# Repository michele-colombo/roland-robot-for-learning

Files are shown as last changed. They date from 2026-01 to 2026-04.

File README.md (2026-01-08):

# ROLAND: a RObot for Learning Autonomous Navigation and Detection
ROLAND is a modular robotics project developed as a learning platform for autonomous navigation, SLAM, sensor fusion, and 3D reconstruction.
The system is built around a differential-drive mobile base and is designed to evolve over time as new sensing, perception, and actuation modules are added.

High-level autonomy runs on an NVIDIA Jetson Orin Nano, while low-level control is handled by an ESP32 driving brushless motors with FOC control.
The robot features self-designed, 3D-printed parts.

## Roadmap
- [x] Differential drive base
- [ ] Add 2D LiDAR and off-the-shelf SLAM module
- [ ] Add stereo camera and 3D mapping of the scene
- [ ] Implement object seeking from image reference
- [ ] Add a manipulator for grabbing the object?

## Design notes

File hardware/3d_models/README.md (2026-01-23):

Original onshape project can be found here: https://cad.onshape.com/documents/1359bf2a92ebeb07a983a6f3/w/c33c9e913b42d0126ce1f26a/e/81632e9f34f59df6b4129b4c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

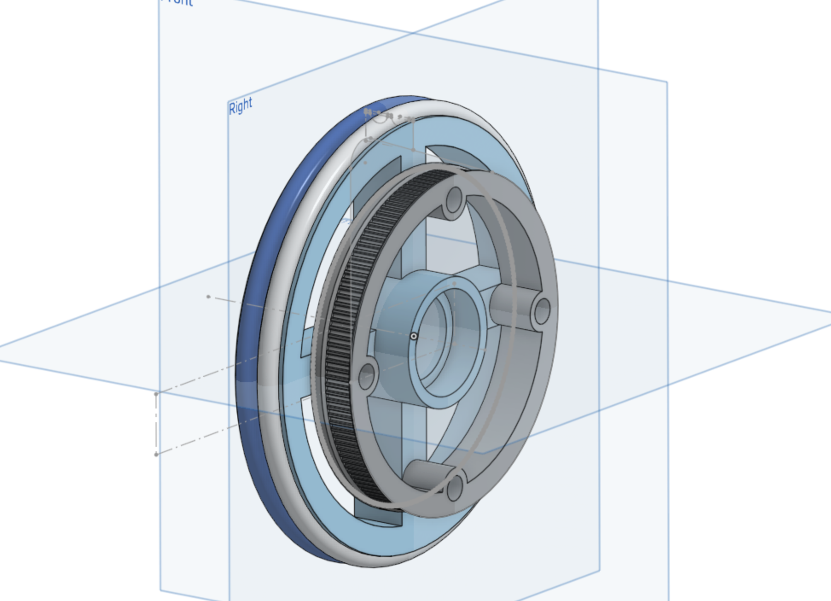
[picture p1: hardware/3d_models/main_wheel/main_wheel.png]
main_wheel


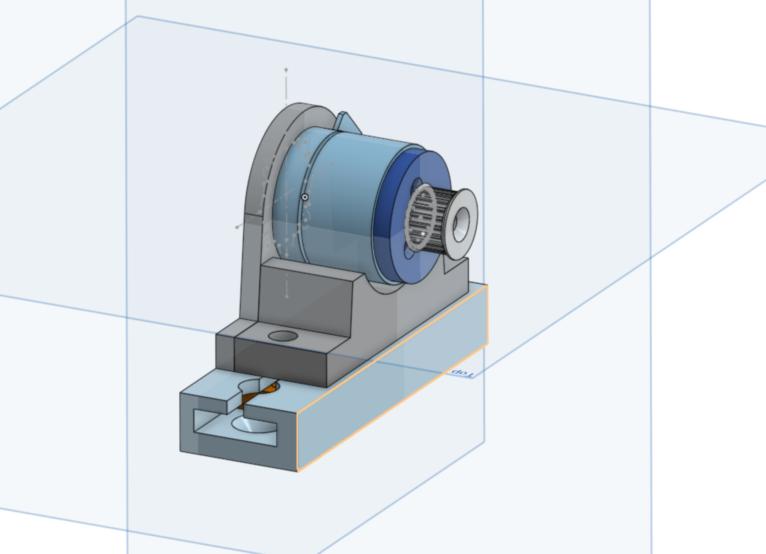
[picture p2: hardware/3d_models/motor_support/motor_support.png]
motor_support


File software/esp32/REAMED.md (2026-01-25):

# ESP32 code

This folder contains code to be uploaded on ESP32(s) to manage low-level interaction with sensors and actuators.

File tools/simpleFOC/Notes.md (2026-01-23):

# Notes
- If you lower the voltage limit (like `motor.voltage_limit = 4;`) you get a lower maximum speed and lower torwue, but also a much smoother and quiter movement (maybe also cooler motor, to check).
- Maybe the speed of the control loop impacts on the motor temperature: it seems that a faster control loop keeps the motor cooler. Probably is asking to the motor a speed higher than the one it can reach that increases temperature.
- You need to call `motor.loopFOC()` at least once before calling `motor.move(target)`, thus they must be in the correct order in the control loop.

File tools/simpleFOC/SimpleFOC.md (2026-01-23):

# SimpleFOC library

## Install SimpleFOC library in Arduino IDE

See the [doc](https://docs.simplefoc.com/library_download).
Briefly:
- Open Arduino IDE and start Arduino Library Manager by clicking: `Tools > Manage Libraries....`
- Search for "Simple FOC" library and install the latest version.
- Reopen Arduino IDE and you should have the library examples in `File > Examples > Simple FOC`.

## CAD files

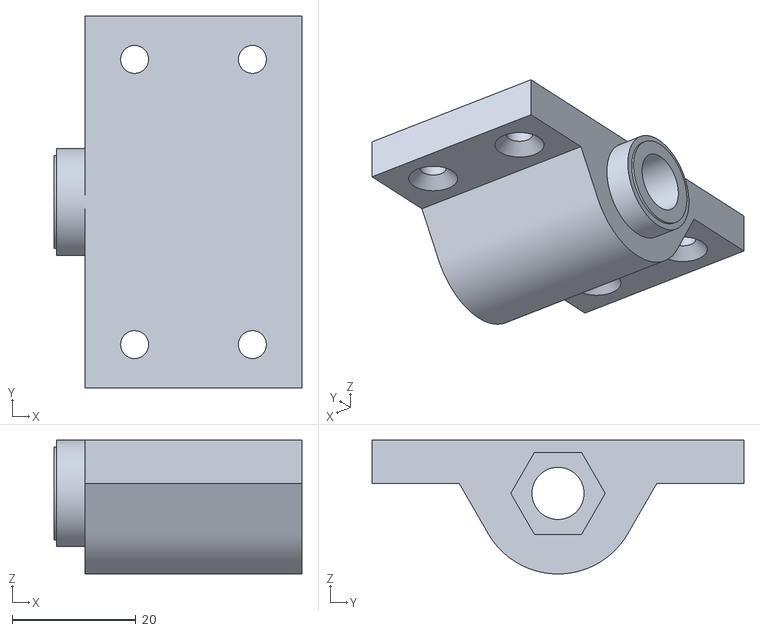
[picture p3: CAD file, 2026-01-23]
hardware/3d_models/main_wheel/main_wheel_support - support.stl
40.0 x 60.0 x 21.6

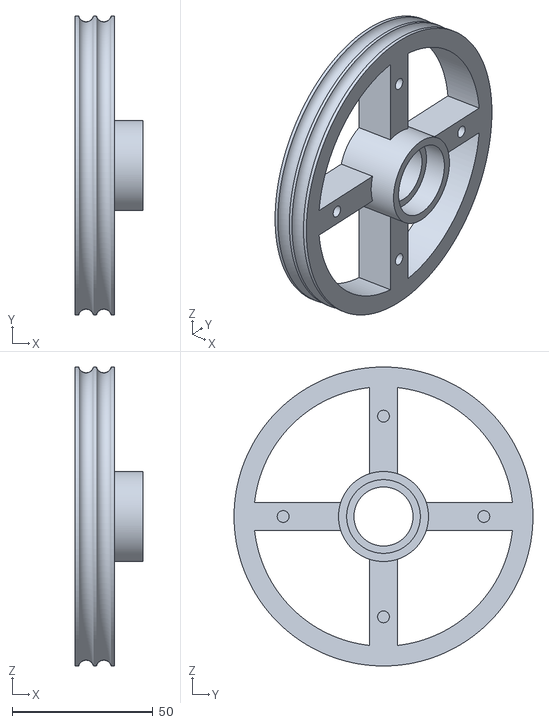
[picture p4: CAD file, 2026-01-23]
hardware/3d_models/main_wheel/main_wheel - wheel.stl
24.0 x 106.3 x 106.3

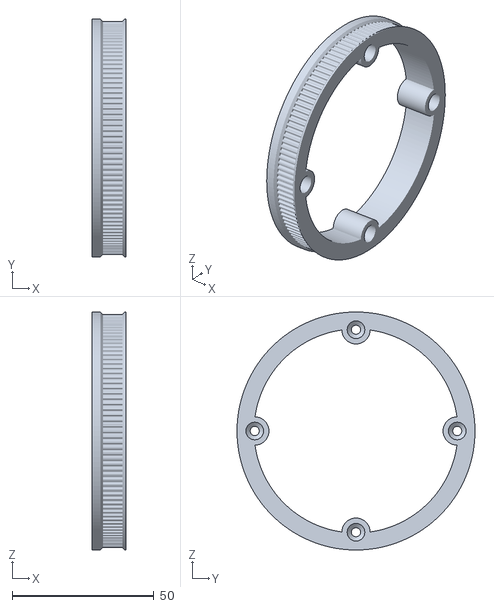
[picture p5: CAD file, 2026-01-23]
hardware/3d_models/main_wheel/main_wheel - pulley.stl
12.0 x 83.9 x 83.9

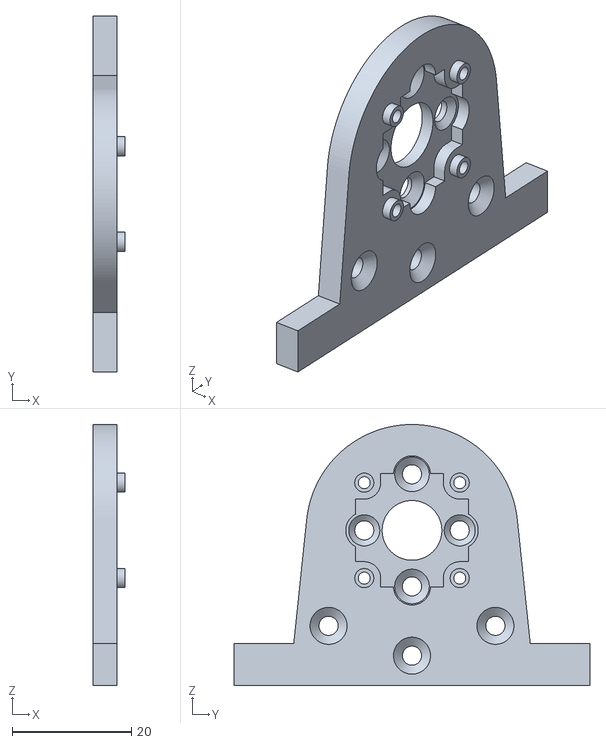
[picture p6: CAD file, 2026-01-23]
hardware/3d_models/motor_support/motor_support - support_1.stl
5.40 x 59.7 x 43.8

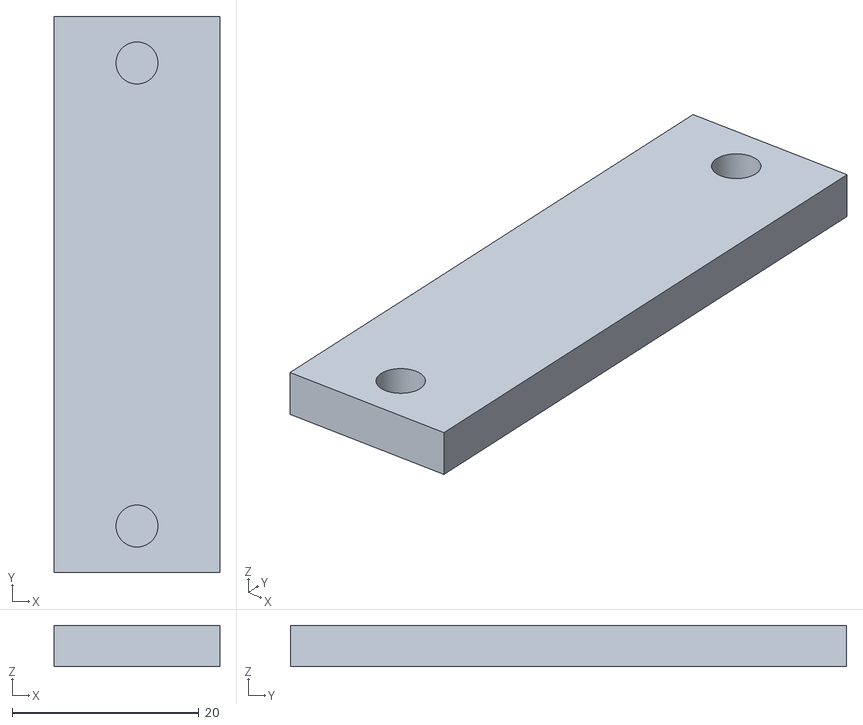
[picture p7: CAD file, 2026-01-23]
hardware/3d_models/motor_support/motor_support - slider_2.stl
17.8 x 59.7 x 4.40

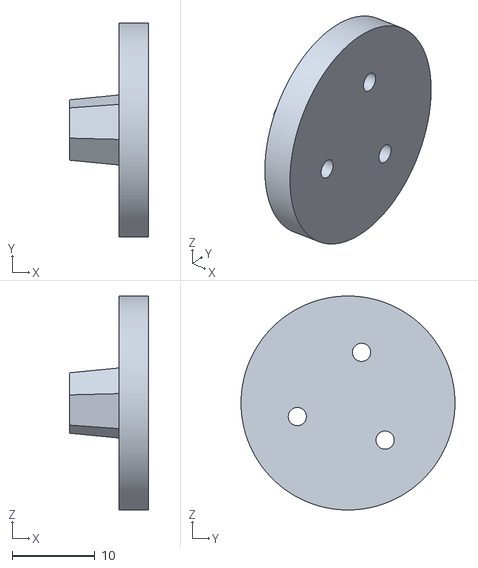
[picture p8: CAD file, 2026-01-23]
hardware/3d_models/motor_support/motor_support - pulley_support.stl
9.60 x 25.9 x 25.9

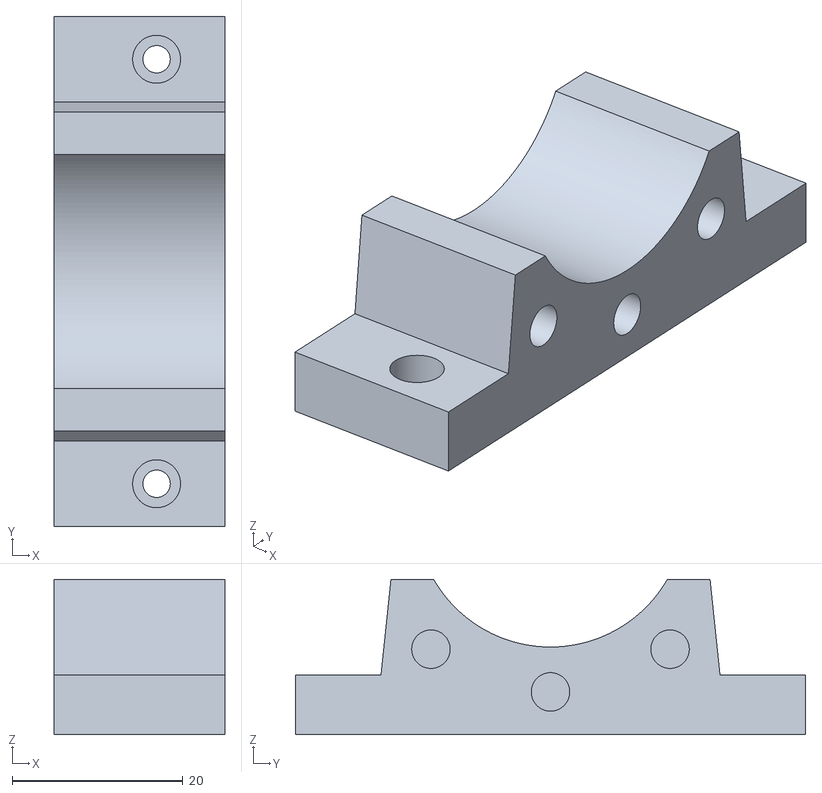
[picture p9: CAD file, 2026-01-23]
hardware/3d_models/motor_support/motor_support - support_2.stl
20.0 x 59.7 x 18.2

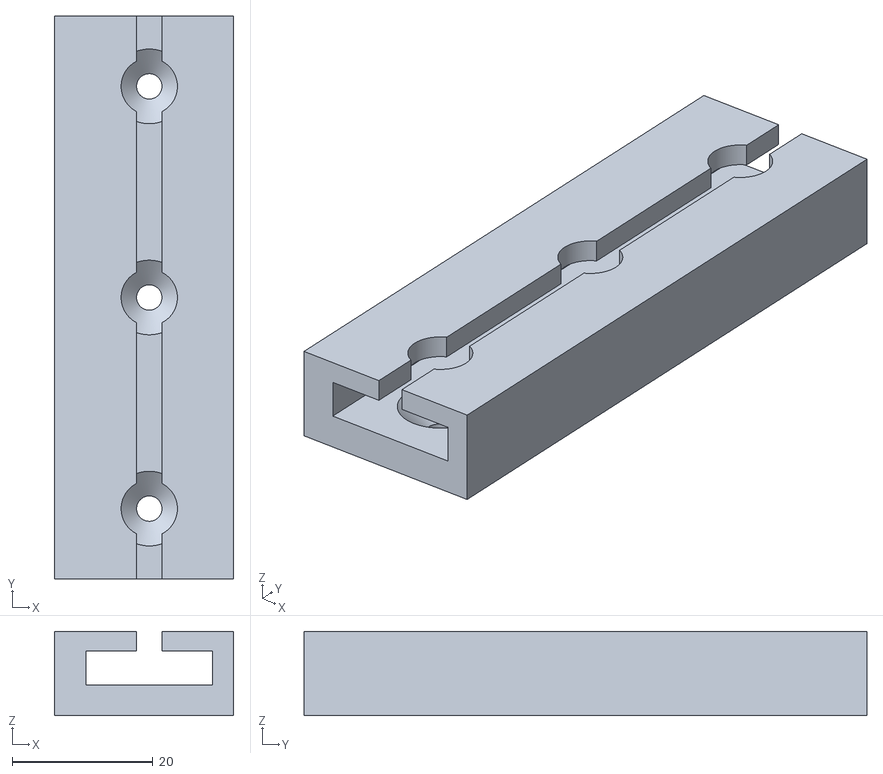
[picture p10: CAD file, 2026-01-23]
hardware/3d_models/motor_support/motor_support - slider.stl
25.5 x 80.0 x 12.0

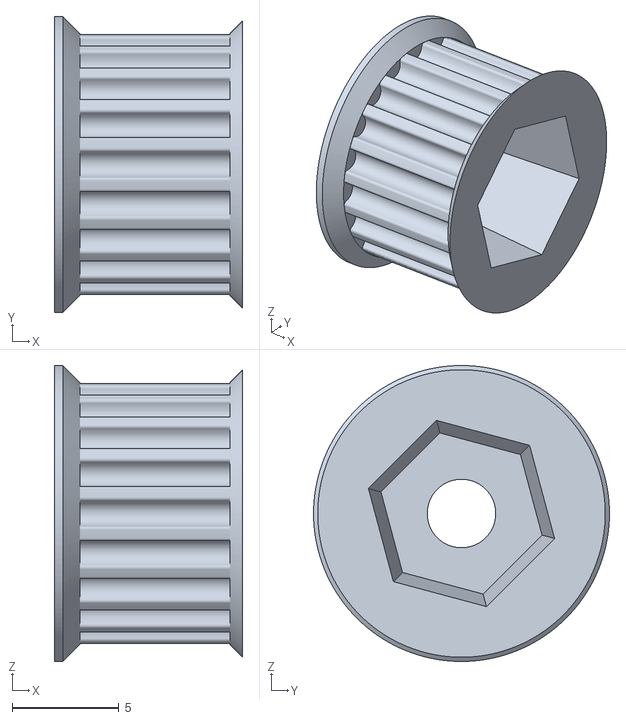
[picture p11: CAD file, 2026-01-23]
hardware/3d_models/motor_support/motor_support - pulley.stl
8.80 x 13.8 x 13.8

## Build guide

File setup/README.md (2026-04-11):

# Setup

## Jetson

- Connect base ESP32, gimbal ESP32, ZED and LiDAR to USB ports of Jetson
- Since both my ESP32 and LiDAR use the same CP2102 chip I cannot use `serial/by-id` to distinguish between them. Therefore I rely on their stable physical connection (you must connect them always to the same port) and use the USB path to the port they are connected to.
    - In order to find the correct USB port path you can use `udevadm monitor --property | grep DEVPATH` and plug/unplug the different devices.
    - Set their address in `setup/jetson/rules/robot.rules`.
    - Run `./setup/jetson/rules/created_udev_rules.sh` to install the rules
    - You should now see `/dev/esp32-base`, `/dev/esp32-gimbal` and `/dev/ldlidar` (with all the devices connected).

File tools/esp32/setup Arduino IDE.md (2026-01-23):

# Setup Arduino IDE (for ESP32)
## Install
Easiest way to get Arduino IDE is probably using flatpak.

```shell
flatpak install flathub cc.arduino.IDE2
```

You may need to add flathub to the current user before (only needed once):
```shell
flatpak remote-add --user --if-not-exists flathub https://flathub.org/repo/flathub.flatpakrepo
```

Add current user to dialout:
```shell
sudo usermod -a -G dialout $USER
```
Then it is necessary to log out and back in.

## Setup for ESP32
 You can check [this tutorial](https://randomnerdtutorials.com/installing-the-esp32-board-in-arduino-ide-windows-instructions/) as reference.

 Basically it's adding the following line in File>Preferences>Additionl Boards Managers URLs:
 ```
 https://raw.githubusercontent.com/espressif/arduino-esp32/gh-pages/package_esp32_index.json, http://arduino.esp8266.com/stable/package_esp8266com_index.json
 ```

 and installing `esp32` board manager by `Expressif Systems` (from Tools > Board > Boards Manager)

 Then select the board. Currently I'm testing with an ESP32-WROOM-32 (from AZ-Delivery) and it works by selecting ESP32-WROOM-DA.

 ## Troubleshooting
 ### Apparent flash failure
 Even if you get an output like this:
```
Writing at 0x000e4078 [============================> ]  98.1% 557056/567916 bytes... 

Writing at 0x000e7ce0 [==============================] 100.0% 567916/567916 bytes... 
Wrote 883936 bytes (567916 compressed) at 0x00010000 in 9.0 seconds (788.8 kbit/s).
Hash of data verified.

Hard resetting via RTS pin...
```
the flashing was actually successful.

### Flash failure
Sometimes flashing fails the first time, usually trying again solves the issue.

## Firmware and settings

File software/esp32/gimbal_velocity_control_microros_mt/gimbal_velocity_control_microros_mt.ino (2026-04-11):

#include <micro_ros_arduino.h>
#include <SimpleFOC.h>

#include <rcl/rcl.h>
#include <rcl/error_handling.h>
#include <rclc/rclc.h>
#include <rclc/executor.h>

#include <std_msgs/msg/float32.h>

// ================================================================
// Pins
// ================================================================
// SPI (AS5048) pins
const int pin_spi_mosi = 23;
const int pin_spi_miso = 19;
const int pin_spi_clk  = 18;
const int pin_cs_yaw   = 2;
const int pin_cs_pitch = 0;

// Yaw motor
const int pin_yaw_in1 = 14;
const int pin_yaw_in2 = 27;
const int pin_yaw_in3 = 26;

// Pitch motor
const int pin_pitch_in1 = 25;
const int pin_pitch_in2 = 33;
const int pin_pitch_in3 = 32;

// ================================================================
// Motor params
// ================================================================
const int   motor_pole_pairs      = 11;
const float motor_phase_resistance = 5.50f / 2.0f;
const float motor_voltage_supply  = 12.0f;
const float motor_voltage_limit   = 6.0f;
const float motor_PID_velocity_P  = 0.2f;
const float motor_PID_velocity_I  = 1.0f;
const float motor_PID_velocity_D  = 0.0f;
const float motor_PID_velocity_output_ramp = 100.0f;
const float motor_LPF_velocity_Tf = 0.05f;

// ================================================================
// micro-ROS
// ================================================================
rclc_executor_t executor;
rclc_support_t support;
rcl_allocator_t allocator;
rcl_node_t node;

rcl_timer_t curr_vel_timer;
const int curr_vel_pub_period = 100; // ms

// ================================================================
// MotorSide
// ================================================================
struct MotorSide
{
  // FOC
  MagneticSensorSPI sensor;
  BLDCMotor motor;
  BLDCDriver3PWM driver;

  // Control
  float targetVelocity;
  float lastAngle;
  bool  initialized;

  // micro-ROS
  const char* cmdTopic;
  const char* currTopic;

  rcl_subscription_t cmdSub;
  rcl_publisher_t    currPub;

  std_msgs__msg__Float32 cmdMsg;
  std_msgs__msg__Float32 currMsg;

  MotorSide(int in1, int in2, int in3, int csPin)
  : sensor(AS5048_SPI, csPin)
  , motor(motor_pole_pairs, motor_phase_resistance)
  , driver(in1, in2, in3)
  , targetVelocity(0.0f)
  , lastAngle(0.0f)
  , initialized(false)
  {}
};

// ================================================================
// Yaw / Pitch motors
// ================================================================
MotorSide motorYaw(
  pin_yaw_in1, pin_yaw_in2, pin_yaw_in3, pin_cs_yaw);

MotorSide motorPitch(
  pin_pitch_in1, pin_pitch_in2, pin_pitch_in3, pin_cs_pitch);

// Convenience array
MotorSide* motors[] = { &motorYaw, &motorPitch };
constexpr int motorCount = 2;

// ================================================================
// micro-ROS callbacks
// ================================================================
void handle_cmd_vel(MotorSide& m, const void* msgin)
{
  const auto* msg = static_cast<const std_msgs__msg__Float32*>(msgin);
  m.targetVelocity = msg->data;
}

void cmd_vel_yaw_cbk(const void* msgin)
{
  handle_cmd_vel(motorYaw, msgin);
}

void cmd_vel_pitch_cbk(const void* msgin)
{
  handle_cmd_vel(motorPitch, msgin);
}

void curr_vel_timer_cbk(rcl_timer_t* timer, int64_t)
{
  if (!timer) return;

  static int64_t lastTime = 0;
  int64_t now = esp_timer_get_time();
  float dt = (now - lastTime) / 1e6f;
  lastTime = now;

  if (dt <= 0.0f) return;

  for (int i = 0; i < motorCount; ++i) {
    MotorSide& m = *motors[i];

    float angle = m.sensor.getAngle();
    float velocity = (angle - m.lastAngle) / dt;
    m.lastAngle = angle;

    m.currMsg.data = velocity;
    rcl_publish(&m.currPub, &m.currMsg, NULL);
  }
}

// ================================================================
// Helpers
// ================================================================

// Safe to call before driver.init(): forces all PWM pins LOW at the GPIO level.
// motor.disable() / driver.disable() must NOT be called before driver.init()
// because driver->params is nullptr until then, causing a null-pointer crash
// inside _writeDutyCycle3PWM on ESP32.
void safeMotorPinsLow()
{
  const int pins[] = {
    pin_yaw_in1,   pin_yaw_in2,   pin_yaw_in3,
    pin_pitch_in1, pin_pitch_in2, pin_pitch_in3
  };
  for (int pin : pins) {
    pinMode(pin, OUTPUT);
    digitalWrite(pin, LOW);
  }
}

void disableAllMotors()
{
  for (int i = 0; i < motorCount; ++i)
    motors[i]->motor.disable();
}

bool allMotorsInitialized()
{
  for (int i = 0; i < motorCount; ++i)
    if (!motors[i]->initialized) return false;
  return true;
}

void initMotor(MotorSide& m)
{
  m.sensor.init();
  m.motor.linkSensor(&m.sensor);

  m.driver.voltage_power_supply = motor_voltage_supply;
  m.driver.init();
  m.motor.linkDriver(&m.driver);

  m.motor.controller = MotionControlType::velocity;
  m.motor.PID_velocity.P = motor_PID_velocity_P;
  m.motor.PID_velocity.I = motor_PID_velocity_I;
  m.motor.PID_velocity.D = motor_PID_velocity_D;
  m.motor.PID_velocity.output_ramp = motor_PID_velocity_output_ramp;
  m.motor.voltage_limit = motor_voltage_limit;
  m.motor.LPF_velocity.Tf = motor_LPF_velocity_Tf;

  m.motor.init();
  m.initialized = m.motor.initFOC();
}

void initMotorRos(MotorSide& m, rclc_subscription_callback_t cbk)
{
  rclc_publisher_init_best_effort(
    &m.currPub,
    &node,
    ROSIDL_GET_MSG_TYPE_SUPPORT(std_msgs, msg, Float32),
    m.currTopic);

  rclc_subscription_init_best_effort(
    &m.cmdSub,
    &node,
    ROSIDL_GET_MSG_TYPE_SUPPORT(std_msgs, msg, Float32),
    m.cmdTopic);

  rclc_executor_add_subscription(
    &executor,
    &m.cmdSub,
    &m.cmdMsg,
    cbk,
    ON_NEW_DATA);
}

// ================================================================
// Tasks
// ================================================================
void ros_loop(void*)
{
  while (1) {
    rclc_executor_spin_some(&executor, RCL_MS_TO_NS(10));
    vTaskDelay(pdMS_TO_TICKS(1));
  }
}

void control_loop(void*)
{
  while (1) {
    for (int i = 0; i < motorCount; ++i) {
      MotorSide& m = *motors[i];
      m.motor.loopFOC();
      m.motor.move(m.targetVelocity);
    }
  }
}

// ================================================================
// Setup
// ================================================================
void setup()
{
  // Force all motor PWM pins low immediately, before anything else.
  // This is to ensure output pins are in a known safe state even if
  // micro-ROS or motor init fails and prevent them from heating up due to DC lock.
  safeMotorPinsLow();

  // micro-ROS (may block here waiting for agent)
  set_microros_transports();

  allocator = rcl_get_default_allocator();
  rclc_support_init(&support, 0, NULL, &allocator);
  rclc_node_init_default(&node, "gimbal_hw_controller", "", &support);

  // Topics
  motorYaw.cmdTopic    = "/gimbal_yaw/cmd_vel";
  motorYaw.currTopic   = "/gimbal_yaw/curr_vel";
  motorPitch.cmdTopic  = "/gimbal_pitch/cmd_vel";
  motorPitch.currTopic = "/gimbal_pitch/curr_vel";

  // Executor: 2 subs + 1 timer
  rclc_executor_init(&executor, &support.context, motorCount + 1, &allocator);

  // Timer
  rclc_timer_init_default(
    &curr_vel_timer,
    &support,
    RCL_MS_TO_NS(curr_vel_pub_period),
    curr_vel_timer_cbk);

  rclc_executor_add_timer(&executor, &curr_vel_timer);

  // ROS entities per motor
  initMotorRos(motorYaw,   cmd_vel_yaw_cbk);
  initMotorRos(motorPitch, cmd_vel_pitch_cbk);

  // Motors
  for (int i = 0; i < motorCount; ++i) {
    initMotor(*motors[i]);
  }

  // Only start tasks if all motors initialized successfully.
  if (!allMotorsInitialized()) {
    disableAllMotors();
    return; // halt here; loop() will idle safely
    // TODO: instead of returning here, send some ros message to notify about the failure
  }

  // Tasks
  xTaskCreatePinnedToCore(
    ros_loop, "ros_loop", 10000, NULL, 5, NULL, 0);

  xTaskCreatePinnedToCore(
    control_loop, "control_loop", 10000, NULL, 10, NULL, 1);
}

void loop()
{
  vTaskDelay(pdMS_TO_TICKS(1000));
}

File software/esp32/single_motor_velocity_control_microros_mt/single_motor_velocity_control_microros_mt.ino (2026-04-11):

#include <micro_ros_arduino.h>
#include <SimpleFOC.h>

#include <rcl/rcl.h>
#include <rcl/error_handling.h>
#include <rclc/rclc.h>
#include <rclc/executor.h>

#include <std_msgs/msg/float32.h>

#define MOTOR_SIDE "right"

// ---------------- Pins ----------------
const int pinDriverIn1 = 25;
const int pinDriverIn2 = 33;
const int pinDriverIn3 = 32;
const int pinDriverEn  = 26;

const int pinSensorSda = 21;
const int pinSensorScl = 22;

// ---------------- Params ----------------
const int   motor_pole_pairs     = 7;
const float motor_voltage_supply = 12.0;
const float motor_voltage_limit  = 6.0;

// ---------------- micro-ROS ----------------
const char node_name[] = "motor_" MOTOR_SIDE "_node";
const char cmd_vel_topic_name[] = "/motor_" MOTOR_SIDE "/cmd_vel";
const char curr_vel_topic_name[] = "/motor_" MOTOR_SIDE "/curr_vel";
rcl_publisher_t curr_vel_pub;
rcl_subscription_t cmd_vel_sub;
rcl_timer_t curr_vel_timer;
int curr_vel_pub_interval = 100; // ms

std_msgs__msg__Float32 curr_vel_msg;
std_msgs__msg__Float32 cmd_vel_msg;

rclc_executor_t executor;
rclc_support_t support;
rcl_allocator_t allocator;
rcl_node_t node;

// ---------------- FOC ----------------
MagneticSensorI2C sensor = MagneticSensorI2C(AS5600_I2C);
BLDCMotor motor = BLDCMotor(motor_pole_pairs);
BLDCDriver3PWM driver = BLDCDriver3PWM(
  pinDriverIn1, pinDriverIn2, pinDriverIn3, pinDriverEn);

// ---------------- Control ----------------
float target_velocity = 0.0f;

// ------------------------------------------------
// Subscriber callbacks
// ------------------------------------------------
void cmd_vel_sub_callback(const void * msgin)
{
  const std_msgs__msg__Float32 * msg =
    (const std_msgs__msg__Float32 *)msgin;

  target_velocity = msg->data;
}

// ------------------------------------------------
// Timer callbacks
// ------------------------------------------------
void curr_vel_timer_callback(
  rcl_timer_t * timer, int64_t last_call_time)
{
  (void) last_call_time;
  if (timer == NULL) {
    return;
  }

  static float last_angle = 0.0f;
  static int64_t last_time = 0;

  float curr_angle = sensor.getAngle();
  int64_t current_time = esp_timer_get_time();

  float velocity = -(curr_angle - last_angle) / ((current_time - last_time) / 1e6f);
  last_angle = curr_angle;
  last_time = current_time;

  curr_vel_msg.data = velocity;
  rcl_publish(&curr_vel_pub, &curr_vel_msg, NULL);

}

// ------------------------------------------------
// ROS executor loop
// ------------------------------------------------
void ros_loop(void *pvParameters)
{
  while (1) {
    rclc_executor_spin_some(&executor, RCL_MS_TO_NS(10));
    vTaskDelay(pdMS_TO_TICKS(1));
  }
}

// ------------------------------------------------
// Real-time FOC loop
// ------------------------------------------------
void control_loop(void *pvParameters)
{
  while (1) {
    motor.loopFOC();
    motor.move(target_velocity);
  }
}

// ------------------------------------------------
// Setup
// ------------------------------------------------
void setup()
{
  set_microros_transports();  

  allocator = rcl_get_default_allocator();
  rclc_support_init(&support, 0, NULL, &allocator);
  rclc_node_init_default(&node, node_name, "", &support);

  // Publisher
  rclc_publisher_init_best_effort(
    &curr_vel_pub,
    &node,
    ROSIDL_GET_MSG_TYPE_SUPPORT(std_msgs, msg, Float32),
    curr_vel_topic_name);

  // Subscriber
  rclc_subscription_init_best_effort(
    &cmd_vel_sub,
    &node,
    ROSIDL_GET_MSG_TYPE_SUPPORT(std_msgs, msg, Float32),
    cmd_vel_topic_name);

  // Timer
  rclc_timer_init_default(
    &curr_vel_timer,
    &support,
    RCL_MS_TO_NS(curr_vel_pub_interval),
    curr_vel_timer_callback);

  // Executor (1 sub + 1 timer)
  rclc_executor_init(&executor, &support.context, 2, &allocator);

  rclc_executor_add_subscription(
    &executor,
    &cmd_vel_sub,
    &cmd_vel_msg,
    &cmd_vel_sub_callback,
    ON_NEW_DATA);

  rclc_executor_add_timer(
    &executor,
    &curr_vel_timer);

  // ----------- FOC setup -----------
  sensor.init();
  motor.linkSensor(&sensor);

  driver.voltage_power_supply = motor_voltage_supply;
  driver.init();
  motor.linkDriver(&driver);

  motor.controller = MotionControlType::velocity;
  motor.PID_velocity.P = 0.05f;
  motor.PID_velocity.I = 1;
  motor.PID_velocity.D = 0;
  motor.voltage_limit = motor_voltage_limit;
  motor.LPF_velocity.Tf = 0.01f;

  motor.init();
  motor.initFOC();

  // ----------- Tasks -----------
  xTaskCreatePinnedToCore(
    ros_loop,
    "ros_loop",
    10000,
    NULL,
    5,
    NULL,
    0);

  xTaskCreatePinnedToCore(
    control_loop,
    "control_loop",
    10000,
    NULL,
    10,
    NULL,
    1);
}

void loop()
{
  vTaskDelay(pdMS_TO_TICKS(1000));
}

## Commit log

2026-01-23 add 3d models
    [main_wheel - pulley.stl, main_wheel - wheel.stl, main_wheel_support - support.stl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]
2026-01-23 add tools and reorganize repo
    [main_wheel - pulley.stl, main_wheel - wheel.stl, main_wheel_support - support.stl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]
2026-01-25 add sketch for controlling single motor (one esp32 for each motor)
2026-02-08 add sketch for controlling two motors using one esp32
2026-02-15 refactor motor sketch (avoid code duplication)
    [two_motors_velocity_control_microros_mt.ino]
2026-02-15 move plotjuggler script and add config
    [motors.xml]
2026-02-15 fix bringup after changing device name
2026-03-29 add initialized flag to motors in order to prevent motors heating up after initialization failure
    [two_motors_velocity_control_microros_mt.ino]
2026-03-29 init output pins to 0 to prevent motor heating in case of micro-ros failure
    [two_motors_velocity_control_microros_mt.ino]
2026-03-31 add simple node for converting twist to motor commands
2026-03-31 refactor: reorganize jetson bringup scripts
2026-04-06 update names of launcher and params in base_control
    [base_controller.yaml]
2026-04-06 add gimbal control (controller and teleop) pkg
    [gimbal_controller.yaml]
2026-04-11 add udev rule for esp32-gimbal
2026-04-11 rename cmd and curr velocity topics and microros nodes
    [motors.xml]
2026-04-11 use wild card in base_controller config
    [base_controller.yaml]
2026-04-11 fix: isolate IncludeLaunchDescription in jetson launch file to avoid params_file cross talk
2026-04-11 change gimbal motor params (reduce noise)
    [gimbal_velocity_control_microros_mt.ino]
